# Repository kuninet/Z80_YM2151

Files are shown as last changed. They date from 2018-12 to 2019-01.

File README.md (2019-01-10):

# Z80マイコン FM音源(YM2151)ボード (KZ80-YM2151)

- SBC8080バスにつながるFM音源ボード KZ80-YM2151 のデータ類です。
- 詳しい説明は以下のwikiを参照してください。
  - https://github.com/kuninet/Z80_YM2151/wiki

## 回路図

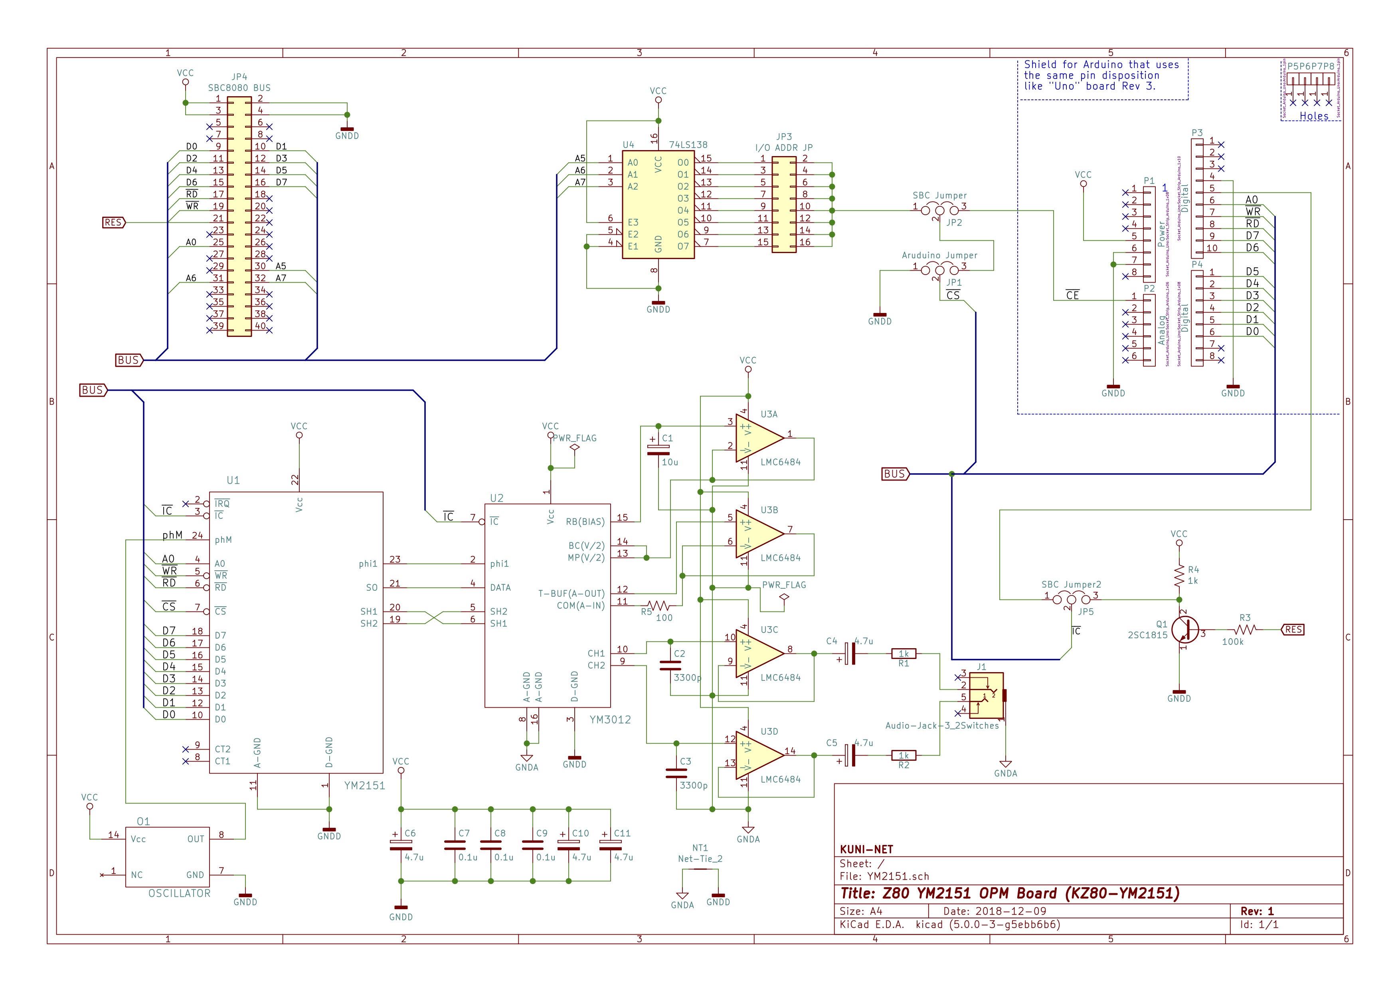
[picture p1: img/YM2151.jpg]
回路図


[PDF版の回路図はこちら](img/YM2151.pdf)

## 部品表

- 部品表は以下にあります。
  - [https://github.com/kuninet/Z80_YM2151/blob/master/KiCAD/YM2151.ods](https://github.com/kuninet/Z80_YM2151/blob/master/KiCAD/YM2151.ods)

## 演奏プログラム&サンプルデータ

- Z80用演奏プログラムとサンプルデータはsample_musicディレクトリにあります。
  - サンプル音楽は参考リンクの音楽データをもとに作成させていただきました。
- 起動方法
  1. sample_music/hexFilesの以下のインテルHex形式ファイルを機械語モニタ等でロード
      - KZ80_YM2151.hex  (8100h番地〜)
      - sample_m.hex    (9000h番地〜)
  2. 8100番地から実行してください。

## 注意点

- 接続方法が複数あり、ジャンパ設定が複雑です。[wiki](https://github.com/kuninet/Z80_YM2151/wiki)をご覧ください。

## ライセンス

- 本リポジトリのデータは MIT License のもとで公開します。

## 参考リンク
- github h1romas4/arduino-vgmplayer
  - https://github.com/h1romas4/arduino-vgmplayer

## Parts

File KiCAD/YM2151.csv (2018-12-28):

Reference | Value | Footprint | Datasheet
P1 | Power | Socket_Arduino_Uno:Socket_Strip_Arduino_1x08
P2 | Analog | Socket_Arduino_Uno:Socket_Strip_Arduino_1x06
P5 | CONN_01X01 | Socket_Arduino_Uno:Arduino_1pin
P6 | CONN_01X01 | Socket_Arduino_Uno:Arduino_1pin
P7 | CONN_01X01 | Socket_Arduino_Uno:Arduino_1pin
P8 | CONN_01X01 | Socket_Arduino_Uno:Arduino_1pin
P4 | Digital | Socket_Arduino_Uno:Socket_Strip_Arduino_1x08
P3 | Digital | Socket_Arduino_Uno:Socket_Strip_Arduino_1x10
U1 | YM2151 | Housings_DIP:DIP-24_W15.24mm_Socket
U2 | YM3012 | Housings_DIP:DIP-16_W7.62mm_Socket
U3 | LMC6484 | Housings_DIP:DIP-14_W7.62mm_Socket
C1 | 10u | Capacitor_THT:CP_Radial_D5.0mm_P2.50mm
C2 | 3300p | Capacitor_THT:C_Disc_D4.3mm_W1.9mm_P5.00mm
C3 | 3300p | Capacitor_THT:C_Disc_D4.3mm_W1.9mm_P5.00mm
C4 | 4.7u | Capacitor_THT:CP_Radial_D5.0mm_P2.50mm
C5 | 4.7u | Capacitor_THT:CP_Radial_D5.0mm_P2.50mm
R1 | 1k | Resistors_THT:R_Axial_DIN0204_L3.6mm_D1.6mm_P7.62mm_Horizontal
R2 | 1k | Resistors_THT:R_Axial_DIN0204_L3.6mm_D1.6mm_P7.62mm_Horizontal
C6 | 4.7u | Capacitor_THT:CP_Radial_D5.0mm_P2.50mm
C7 | 0.1u | Capacitor_THT:C_Disc_D3.0mm_W1.6mm_P2.50mm
C8 | 0.1u | Capacitor_THT:C_Disc_D3.0mm_W1.6mm_P2.50mm
C10 | 4.7u | Capacitor_THT:CP_Radial_D5.0mm_P2.50mm
JP1 | Aruduino Jumper | Connector_PinHeader_2.54mm:PinHeader_1x03_P2.54mm_Vertical
J1 | Audio-Jack-3_2Switches | AJ-1780:AJ-1780
O1 | OSCILLATOR | Oscillator:Oscillator_DIP-14
NT1 | Net-Tie_2 | NetTie:NetTie-2_SMD_Pad2.0mm | ~
JP4 | SBC8080 BUS | Connector_PinHeader_2.54mm:PinHeader_2x20_P2.54mm_Horizontal | ~
JP2 | SBC Jumper | Connector_PinHeader_2.54mm:PinHeader_1x03_P2.54mm_Vertical
JP3 | I/O ADDR JP | Connector_PinHeader_2.54mm:PinHeader_2x08_P2.54mm_Vertical | ~
U4 | 74LS138 | Package_DIP:DIP-16_W7.62mm_Socket | http://www.ti.com/lit/gpn/sn74LS138
R3 | 100k | Resistor_THT:R_Axial_DIN0204_L3.6mm_D1.6mm_P7.62mm_Horizontal | ~
R4 | 1k | Resistor_THT:R_Axial_DIN0204_L3.6mm_D1.6mm_P7.62mm_Horizontal | ~
Q1 | 2SC1815 | Package_TO_SOT_THT:TO-92_Inline_Wide | https://media.digikey.com/pdf/Data%20Sheets/Toshiba%20PDFs/2SC1815.pdf
C9 | 0.1u | Capacitor_THT:C_Disc_D3.0mm_W1.6mm_P2.50mm
C11 | 4.7u | Capacitor_THT:CP_Radial_D5.0mm_P2.50mm
R5 | 100 | Resistor_THT:R_Axial_DIN0204_L3.6mm_D1.6mm_P7.62mm_Horizontal | ~
JP5 | SBC Jumper2 | Connector_PinHeader_2.54mm:PinHeader_1x03_P2.54mm_Vertical

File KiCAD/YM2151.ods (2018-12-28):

部品番号 | 仕様 | 数量 | 代替可能品 | Footprint
P1 | 1列x8 ピンヘッダ等 | 1 |  | Socket_Arduino_Uno:Socket_Strip_Arduino_1x08
P2 | 1列x6 ピンヘッダ等 | 1 |  | Socket_Arduino_Uno:Socket_Strip_Arduino_1x06
P4 | 1列x8 ピンヘッダ等 | 1 |  | Socket_Arduino_Uno:Socket_Strip_Arduino_1x08
P3 | 1列x10 ピンヘッダ等 | 1 |  | Socket_Arduino_Uno:Socket_Strip_Arduino_1x10
U1 | YM2151 | 1 | - | Housings_DIP:DIP-24_W15.24mm_Socket
U2 | YM3012 | 1 | - | Housings_DIP:DIP-16_W7.62mm_Socket
U3 | LMC6484 | 1 | LMC660CN等 4回路入 単一電源オペアンプ | Housings_DIP:DIP-14_W7.62mm_Socket
U4 | 74HC138 | 1 | 74HCT138 | Package_DIP:DIP-16_W7.62mm_Socket
C1 | 10uF | 1 | 電解コンデンサ | Capacitor_THT:CP_Radial_D5.0mm_P2.50mm
C2、C3 | 3300p | 2 | フィルム or 積層セラミックコンデンサ | Capacitor_THT:C_Disc_D4.3mm_W1.9mm_P5.00mm
C4、C5、C6、C10、C11 | 4.7u | 5 | 電解コンデンサ | Capacitor_THT:CP_Radial_D5.0mm_P2.50mm
C7、C8、C9 | 0.1u | 3 | 積層セラミックコンデンサ | Capacitor_THT:C_Disc_D3.0mm_W1.6mm_P2.50mm
R1、R2、R4 | 1kΩ | 3 | 1/4W カーボン抵抗器 | Resistors_THT:R_Axial_DIN0204_L3.6mm_D1.6mm_P7.62mm_Horizontal
R3 | 100kΩ | 1 | 1/4W カーボン抵抗器 | Resistor_THT:R_Axial_DIN0204_L3.6mm_D1.6mm_P7.62mm_Horizontal
R5 | 100Ω | 1 | 1/4W カーボン抵抗器 | Resistor_THT:R_Axial_DIN0204_L3.6mm_D1.6mm_P7.62mm_Horizontal
J1 | AJ-1780 | 1 | オーディオジャック | AJ-1780:AJ-1780
JP1 | 1列x3 ピンヘッダ | 1 |  | Connector_PinHeader_2.54mm:PinHeader_1x03_P2.54mm_Vertical
JP2 | 1列x3 ピンヘッダ | 1 |  | Connector_PinHeader_2.54mm:PinHeader_1x03_P2.54mm_Vertical
JP3 | 2列x8 ピンヘッダ | 1 |  | Connector_PinHeader_2.54mm:PinHeader_2x08_P2.54mm_Vertical
JP4 | 40pin L型ボックスヘッダ | 1 |  | Connector_PinHeader_2.54mm:PinHeader_2x20_P2.54mm_Horizontal
JP5 | 1列x3 ピンヘッダ | 1 |  | Connector_PinHeader_2.54mm:PinHeader_1x03_P2.54mm_Vertical
Q1 | 2SC1815 | 1 | 2SC1815同等品 | Package_TO_SOT_THT:TO-92_Inline_Wide
O1 | 3.579545MHz 水晶発振器 | 1 | 水晶発振器 (DIP14ピンサイズ) | Oscillator:Oscillator_DIP-14

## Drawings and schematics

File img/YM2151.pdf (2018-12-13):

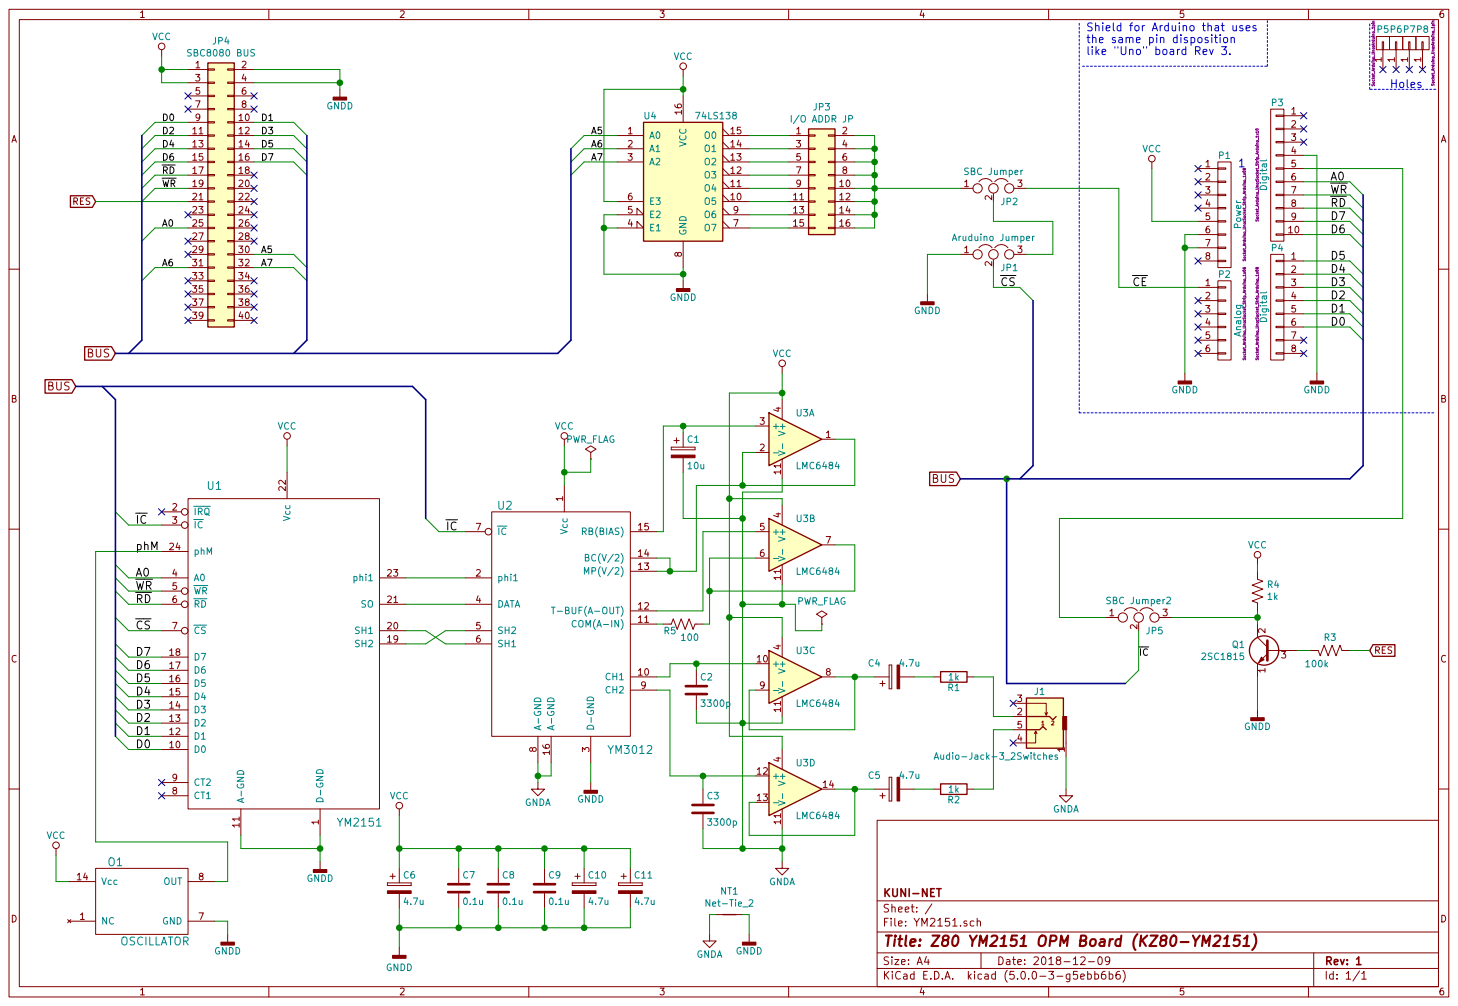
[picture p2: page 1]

Holes Shield for Arduino that uses
the same pin disposition
like "Uno" board Rev 3. 1

11 | 12
13 | 14
15 | 16

8 CH2 9 U2 YM3012 GNDD GNDA GNDD BUS

Id: 1/1 Title: Z80 YM2151 OPM Board (KZ80-YM2151) File: YM2151.sch Sheet: / KUNI-NET

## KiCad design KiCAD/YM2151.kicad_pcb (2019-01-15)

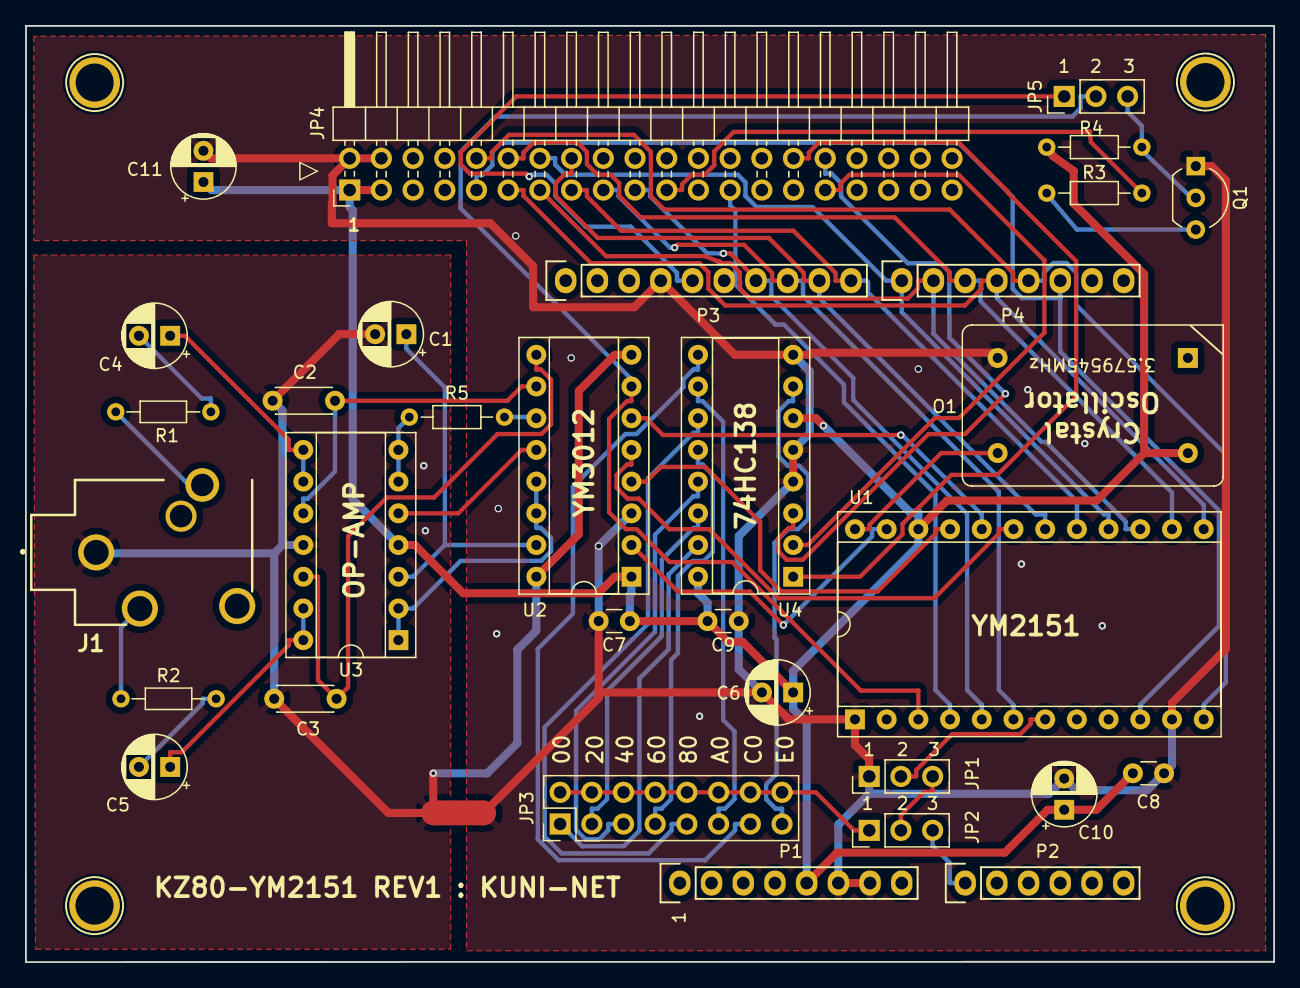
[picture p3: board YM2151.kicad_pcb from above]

Board: 2 copper layers, 100.0 x 75.0 mm, 37 parts (0 on the bottom side), 52 nets.

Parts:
C1: 10u; CP_Radial_D5.0mm_P2.50mm
C2, C3: 3300p; C_Disc_D4.3mm_W1.9mm_P5.00mm
C4, C5, C6, C10, C11: 4.7u; CP_Radial_D5.0mm_P2.50mm
C7, C8, C9: 0.1u; C_Disc_D3.0mm_W1.6mm_P2.50mm
J1: Audio-Jack-3_2Switches; AJ-1780
JP1: Aruduino Jumper; PinHeader_1x03_P2.54mm_Vertical
JP2: SBC Jumper; PinHeader_1x03_P2.54mm_Vertical
JP3: I/O ADDR JP; PinHeader_2x08_P2.54mm_Vertical
JP4: SBC8080 BUS; PinHeader_2x20_P2.54mm_Horizontal
JP5: SBC Jumper2; PinHeader_1x03_P2.54mm_Vertical
NT1: Net-Tie_2; NetTie-2_SMD_Pad2.0mm
O1: OSCILLATOR; Oscillator_DIP-14
P1: Power; Socket_Strip_Arduino_1x08
P2: Analog; Socket_Strip_Arduino_1x06
P3: Digital; Socket_Strip_Arduino_1x10
P4: Digital; Socket_Strip_Arduino_1x08
P5, P6, P7, P8: CONN_01X01; Arduino_1pin
Q1: 2SC1815; TO-92_Inline_Wide
R1, R2, R4: 1k; R_Axial_DIN0204_L3.6mm_D1.6mm_P7.62mm_Horizontal
R3: 100k; R_Axial_DIN0204_L3.6mm_D1.6mm_P7.62mm_Horizontal
R5: 100; R_Axial_DIN0204_L3.6mm_D1.6mm_P7.62mm_Horizontal
U1: YM2151; DIP-24_W15.24mm_Socket
U2: YM3012; DIP-16_W7.62mm_Socket
U3: LMC6484; DIP-14_W7.62mm_Socket
U4: 74LS138; DIP-16_W7.62mm_Socket

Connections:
/A0: JP4.25, P3.6, U1.4
/A5: JP4.30, U4.1
/A6: JP4.31, U4.2
/A7: JP4.32, U4.3
/D0: JP4.9, P4.6, U1.10
/D1: JP4.10, P4.5, U1.12
/D2: JP4.11, P4.4, U1.13
/D3: JP4.12, P4.3, U1.14
/D4: JP4.13, P4.2, U1.15
/D5: JP4.14, P4.1, U1.16
/D6: JP4.15, P3.10, U1.17
/D7: JP4.16, P3.9, U1.18
/phM: O1.8, U1.24
/~CE: JP2.3, P2.1
/~CS: JP1.2, U1.7
/~IC: JP5.2, U1.3, U2.7
/~RD: JP4.17, P3.8, U1.6
/~WR: JP4.19, P3.7, U1.5
GNDA: C1.2, C2.2, C3.2, J1.1, NT1.1, U2.8, U2.16, U3.11
GNDD: C6.2, C7.2, C8.2, C9.2, C10.2, C11.2, JP1.1, JP4.2, JP4.4, NT1.2, O1.7, P1.6, P1.7, P3.4, Q1.1, U1.1, U1.11, U2.3, U4.4, U4.5, U4.8
unnamed: C1.1, U2.15, U3.3
unnamed: C2.1, U2.10, U3.10
unnamed: C3.1, U2.9, U3.12
unnamed: C4.1, U3.8, U3.9
unnamed: C4.2, R1.2
unnamed: C5.1, U3.13, U3.14
unnamed: C5.2, R2.2
unnamed: J1.2, R1.1
unnamed: J1.5, R2.1
unnamed: JP1.3, JP2.2
unnamed: JP2.1, JP3.2, JP3.4, JP3.6, JP3.8, JP3.10, JP3.12, JP3.14, JP3.16
unnamed: JP3.1, U4.15
unnamed: JP3.3, U4.14
unnamed: JP3.5, U4.13
unnamed: JP3.7, U4.12
unnamed: JP3.9, U4.11
unnamed: JP3.11, U4.10
unnamed: JP3.13, U4.9
unnamed: JP3.15, U4.7
unnamed: JP5.1, P3.5
unnamed: JP5.3, Q1.2, R4.1
unnamed: Q1.3, R3.1
unnamed: R5.1, U3.6, U3.7
unnamed: R5.2, U2.11
unnamed: U1.19, U2.5
unnamed: U1.20, U2.6
unnamed: U1.21, U2.4
unnamed: U1.23, U2.2
unnamed: U2.12, U3.5
unnamed: U2.13, U2.14, U3.1, U3.2
RES: JP4.21, R3.2
VCC: C6.1, C7.1, C8.1, C9.1, C10.1, C11.1, JP4.1, JP4.3, O1.14, P1.5, R4.2, U1.22, U2.1, U3.4, U4.6, U4.16

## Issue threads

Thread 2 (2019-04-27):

サンプル演奏プログラムでステータスチェック後にメモリー破壊

kuninet, 2019-04-27:
# 内容
- サンプル演奏プログラム[KZ80_YM2151.ASM](https://github.com/kuninet/Z80_YM2151/blob/master/sample_music/src/KZ80_YM2151.ASM)で、OPNのステータスチェック後のロジックでメモリーを破壊するバグあり。

```
WRITEOPN:
; STATUS CHECK WAIT
    IN  A,(OPM_DATA)
    LD	(IX+0),A
    INC  IX
    RLCA
    JR      C,WRITEOPN
```

kuninet, 2019-05-01:
対応完了!

Closed 2019-05-01.

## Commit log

2018-12-13 init commit
    [YM2151-2018-09-22-20-20-13.sch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]
2018-12-13 KiCADデータ・ディレクトリ移動
    [YM2151-2018-09-22-20-20-13.sch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]
2018-12-13 README追加
2018-12-13 回路図イメージ等追加
2018-12-28 部品表整備
    [YM2151.csv, YM2151.ods, YM2151.sch]
2018-12-31 README更新
2019-01-09 サンプル演奏データ/PGM 追加
2019-01-09 readme誤記修正
2019-01-10 演奏プログラム開始番地変更
2019-01-10 シルクパターン等整備
    [YM2151.kicad_pcb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]
2019-01-15 クリスタル部分のシルクパターン見直し
    [YM2151.kicad_pcb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]
2019-04-28 #1 演奏プログラムバグ修正 & サンブルミュージック追加
2019-04-28 サンプルミュージック 元データ修正をうけて再作成
2019-05-01 #2 演奏プログラムバグ修正 & サンブルミュージック追加
